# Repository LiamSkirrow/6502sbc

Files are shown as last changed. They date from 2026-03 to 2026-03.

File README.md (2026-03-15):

# 6502 🎉

A minimal implementation of a functional 6502-based system. It has everything that's needed to get going, including a 6522 VIA (for parallel ports/GPIO control) and a 6551 ACIA (for uart connection to a serial terminal).

## Pics
TODO, include screenshots of schematic and PCB. Can I render these automatically based on the current state of the schem/pcb in the repo?

## Memory Map
TODO

## Bootloader
ASM TODO

## Components
TODO

## Tutorial, how to get up and running
TODO, sourcing components, board bring-up, writing your own ASM snippets and loading them into ram via the bootloader+serial chip. How to write your own ISRs etc.

### Development Notes
- consider replacing zero-Ohm resistors with jumper headers, so I can place/replace them without a soldering iron
- add a jumper header to be able to switch between powering the board directly via a 5V USB cable, and an LM7805 linear reg. Three way jumper header to make it impossible to simultaneously select both options.
- rework memory map so that the ROM is only large enough to contain the minimal bootloader (+ a little extra just in case). We only need the ROM to be as large as the bootloader, since the RAM is where the user-code will be loaded into ready for execution, so minimise ROM and maximise RAM util.
  - perhaps rather than sacrifice a small but fixed amount of memory to the bootloader, why not think of a way to utilise the full 64kB RAM chip once the bootloader has completed. There would need to be some kind of dynamic bank-switching involved, possibly involving one output bit of the 6522 GPIO port to adjust the address decoding to no longer enable the ROM, instead always enabling the RAM (except obviously for when accessing the 6522/6551). So, when the bootloader completes and jumps to the starting address of the user program (in RAM), the first instructions should write to a special GPIO bit that switches out the default decode logic for another logic function that keeps the ROM disabled and RAM enabled. This way, we'd be able to utilise the full ROM space and then when its job is complete we could switch to utilising the full RAM space. So we don't need to use small, fixed regions of memory at any one time, instead using potentially the full capacity of the chip.

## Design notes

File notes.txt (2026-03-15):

SIGN OFF CHECKS:
- consider a PCB solder mask colour other than green?
- consider socketing the crystal? so different crystals can be swapped in and out
- add some gnd test hooks for scope probe
- add jumper header to input current path
- make sure EEPROM has enough space for ZIF socket
- address all text on schematic...
- it looks like you can tie RTS to CTS, DSR to DTR to DCD (https://www.youtube.com/watch?v=XVEnxipCIJ0&ab_channel=UnistInc.), make sure each of these signals on the pin header are next to eachother so they can be tied together via a shunt connector if need be
- read through notes on phone, pay attention to each point individually
- what's the deal with the flow control pins? can you just tie them 'inactive' and forget about it???
- EEPROM should be fitted in a ZIF socket
- *** should I put the ZIF socket in a normal dip socket, so the ZIF socket can be removed eventually? ***
- *** verify that ALL packages are actually available to buy BEFORE placing PCB order ***

BOM SIGN OFF CHECKS:
- buy some female-female wires, female-male wires
- at end of PCB layout count up how many 0603 components are being used, check you still have enough in stock (100nF caps...)
- *** verify that ALL packages are actually available to buy BEFORE placing PCB order ***
- check the forward voltage of the 0805 LEDs, resize resistors if necessary
- all parts should be HC *not* HCT or TTL 

Soldering order of components:
- linear regulator
- push button/debounce circuitry
- decode logic + pin headers for address bus access
- clock circuit
- everything else...

MUST DO:
- To verify: (simulation???)
  - clock circuit

- ??? what's the advantage of gating the PHI2 signal -> *** https://wilsonminesco.com/6502primer/addr_decoding.html ***
- verify all the IO chip's max clock frequency capability, run system at max possible frequency

Footprints:
Might need to change:
- LED resistors
- verify crystal footprints

Memory Map:
  ZP     0x0000 - 0x00FF (256 Bytes)
  STACK  0x0100 - 0x01FF (256 Bytes)
  I/O    0x0200 - 0x021F (32 Bytes) 
  - 6551   0x0200 - 0x020F (16 Bytes)
  - 6522   0x0200 - 0x021F (16 Bytes)
  MEM    0x0220 - 0x7FFF (32,224 Bytes)
  -------------------------------------
  ROM    0x8000 - 0xFFFF (32 kBytes)

$$$
if:
- ~13cm x ~15cm
- 4 layer board
- 1.6mm thickness
= $56.29

else:
- 2 layer
= ~$15
$$$

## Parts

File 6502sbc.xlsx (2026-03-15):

Reference | Quantity | Value | Footprint | DONE?
C1 | 1 | 0.22u | Capacitor_SMD:C_0805_2012Metric_Pad1.18x1.45mm_HandSolder | Y
C2 | 1 | 0.1u | Capacitor_SMD:C_0603_1608Metric_Pad1.08x0.95mm_HandSolder | Y
C3 C4 C5 C7 C8 C10 C11 C12 C13 C14 | 10 | 100n | Capacitor_SMD:C_0603_1608Metric_Pad1.08x0.95mm_HandSolder | Y
C6 C15 | 2 | 1u | Capacitor_SMD:C_0805_2012Metric_Pad1.18x1.45mm_HandSolder | Y
C9 | 1 | 30p | Capacitor_SMD:C_0805_2012Metric_Pad1.18x1.45mm_HandSolder | Y
D1 D2 D3 D4 D5 D6 D7 D8 D9 | 9 | LED | LED_SMD:LED_0805_2012Metric_Pad1.15x1.40mm_HandSolder | Y
J1 J3 | 2 | Conn_02x16_Odd_Even | Connector_PinHeader_2.54mm:PinHeader_2x16_P2.54mm_Vertical | Y
J2 | 1 | Conn_01x02 | Connector_PinHeader_2.54mm:PinHeader_1x02_P2.54mm_Vertical | Y
J6 J7 J8 | 3 | Conn_01x03_Male | Connector_PinHeader_2.54mm:PinHeader_1x03_P2.54mm_Vertical | Y
R1 | 1 | 500 | Resistor_SMD:R_0805_2012Metric_Pad1.20x1.40mm_HandSolder | Y
R9 R10 R11 R12 R13 R14 R15 R16 | 8 | 600 | Resistor_SMD:R_0603_1608Metric_Pad1.05x0.95mm_HandSolder | Y
R19 | 1 | 15k | Resistor_SMD:R_0805_2012Metric_Pad1.20x1.40mm_HandSolder | Y
R2 R3 R17 R18 | 4 | 1k | Resistor_SMD:R_0805_2012Metric_Pad1.20x1.40mm_HandSolder | Y
R4 | 1 | 1.5k | Resistor_SMD:R_0805_2012Metric_Pad1.20x1.40mm_HandSolder | Y
R5 | 1 | 3k | Resistor_SMD:R_0805_2012Metric_Pad1.20x1.40mm_HandSolder | Y
R6 R7 R8 | 3 | 3.3k | Resistor_SMD:R_0805_2012Metric_Pad1.20x1.40mm_HandSolder | Y
R20 | 1 | 1M | Resistor_SMD:R_0805_2012Metric_Pad1.20x1.40mm_HandSolder | Y
SW1 SW2 | 2 | SW_Push | Button_Switch_SMD:SW_Push_1P1T_NO_6x6mm_H9.5mm | Y
U1 | 1 | LM7805_TO220 | Package_TO_SOT_THT:TO-220-3_Vertical | Y
U10 | 1 | 74HCT541 | Package_SO:SOIC-20W_7.5x12.8mm_P1.27mm | Y
U2 | 1 | 6502 | Package_DIP:DIP-40_W15.24mm | Y
U3 | 1 | 6522 | Package_DIP:DIP-40_W15.24mm | Y
U4 | 1 | 6551 | Package_DIP:DIP-28_W15.24mm | Y
U5 | 1 | 4081 | Package_SO:SOIC-14W_7.5x9.0mm_P1.27mm | Y
U6 U12 | 2 | 4002 | Package_SO:SOIC-14W_7.5x9.0mm_P1.27mm | Y
U7 | 1 | 28C256 | Package_DIP:DIP-28_W15.24mm | Y
U8 | 1 | FM1808B-SG | Package_DIP:DIP-28_W15.24mm | Y
U9 U11 | 2 | 74HC14 | Package_SO:SOIC-14W_7.5x9.0mm_P1.27mm | Y
Y1 | 1 | 1MHz | Crystal:Resonator-2Pin_W6.0mm_H3.0mm | Y
Y2 | 1 | 1.8432MHz | Crystal:Resonator-2Pin_W6.0mm_H3.0mm | Y
R21 R22 R23 | 3 | 0Ohm | 805 | Y
ADDITIONAL COMPONENTS |  | REFER TO DEV NOTES (shunts etc…)
2 way shunt header | 2 |  |  | Y
3 way shunt header | 1 |  |  | N | going with 0 ohm resistors instead
f-f wires | 16 |  |  | Y
f-m wires | 16 |  |  | Y
stand off legs | 4 |  |  | Y
ZIF socket | 1
soldering tweezers |  |  |  | Y

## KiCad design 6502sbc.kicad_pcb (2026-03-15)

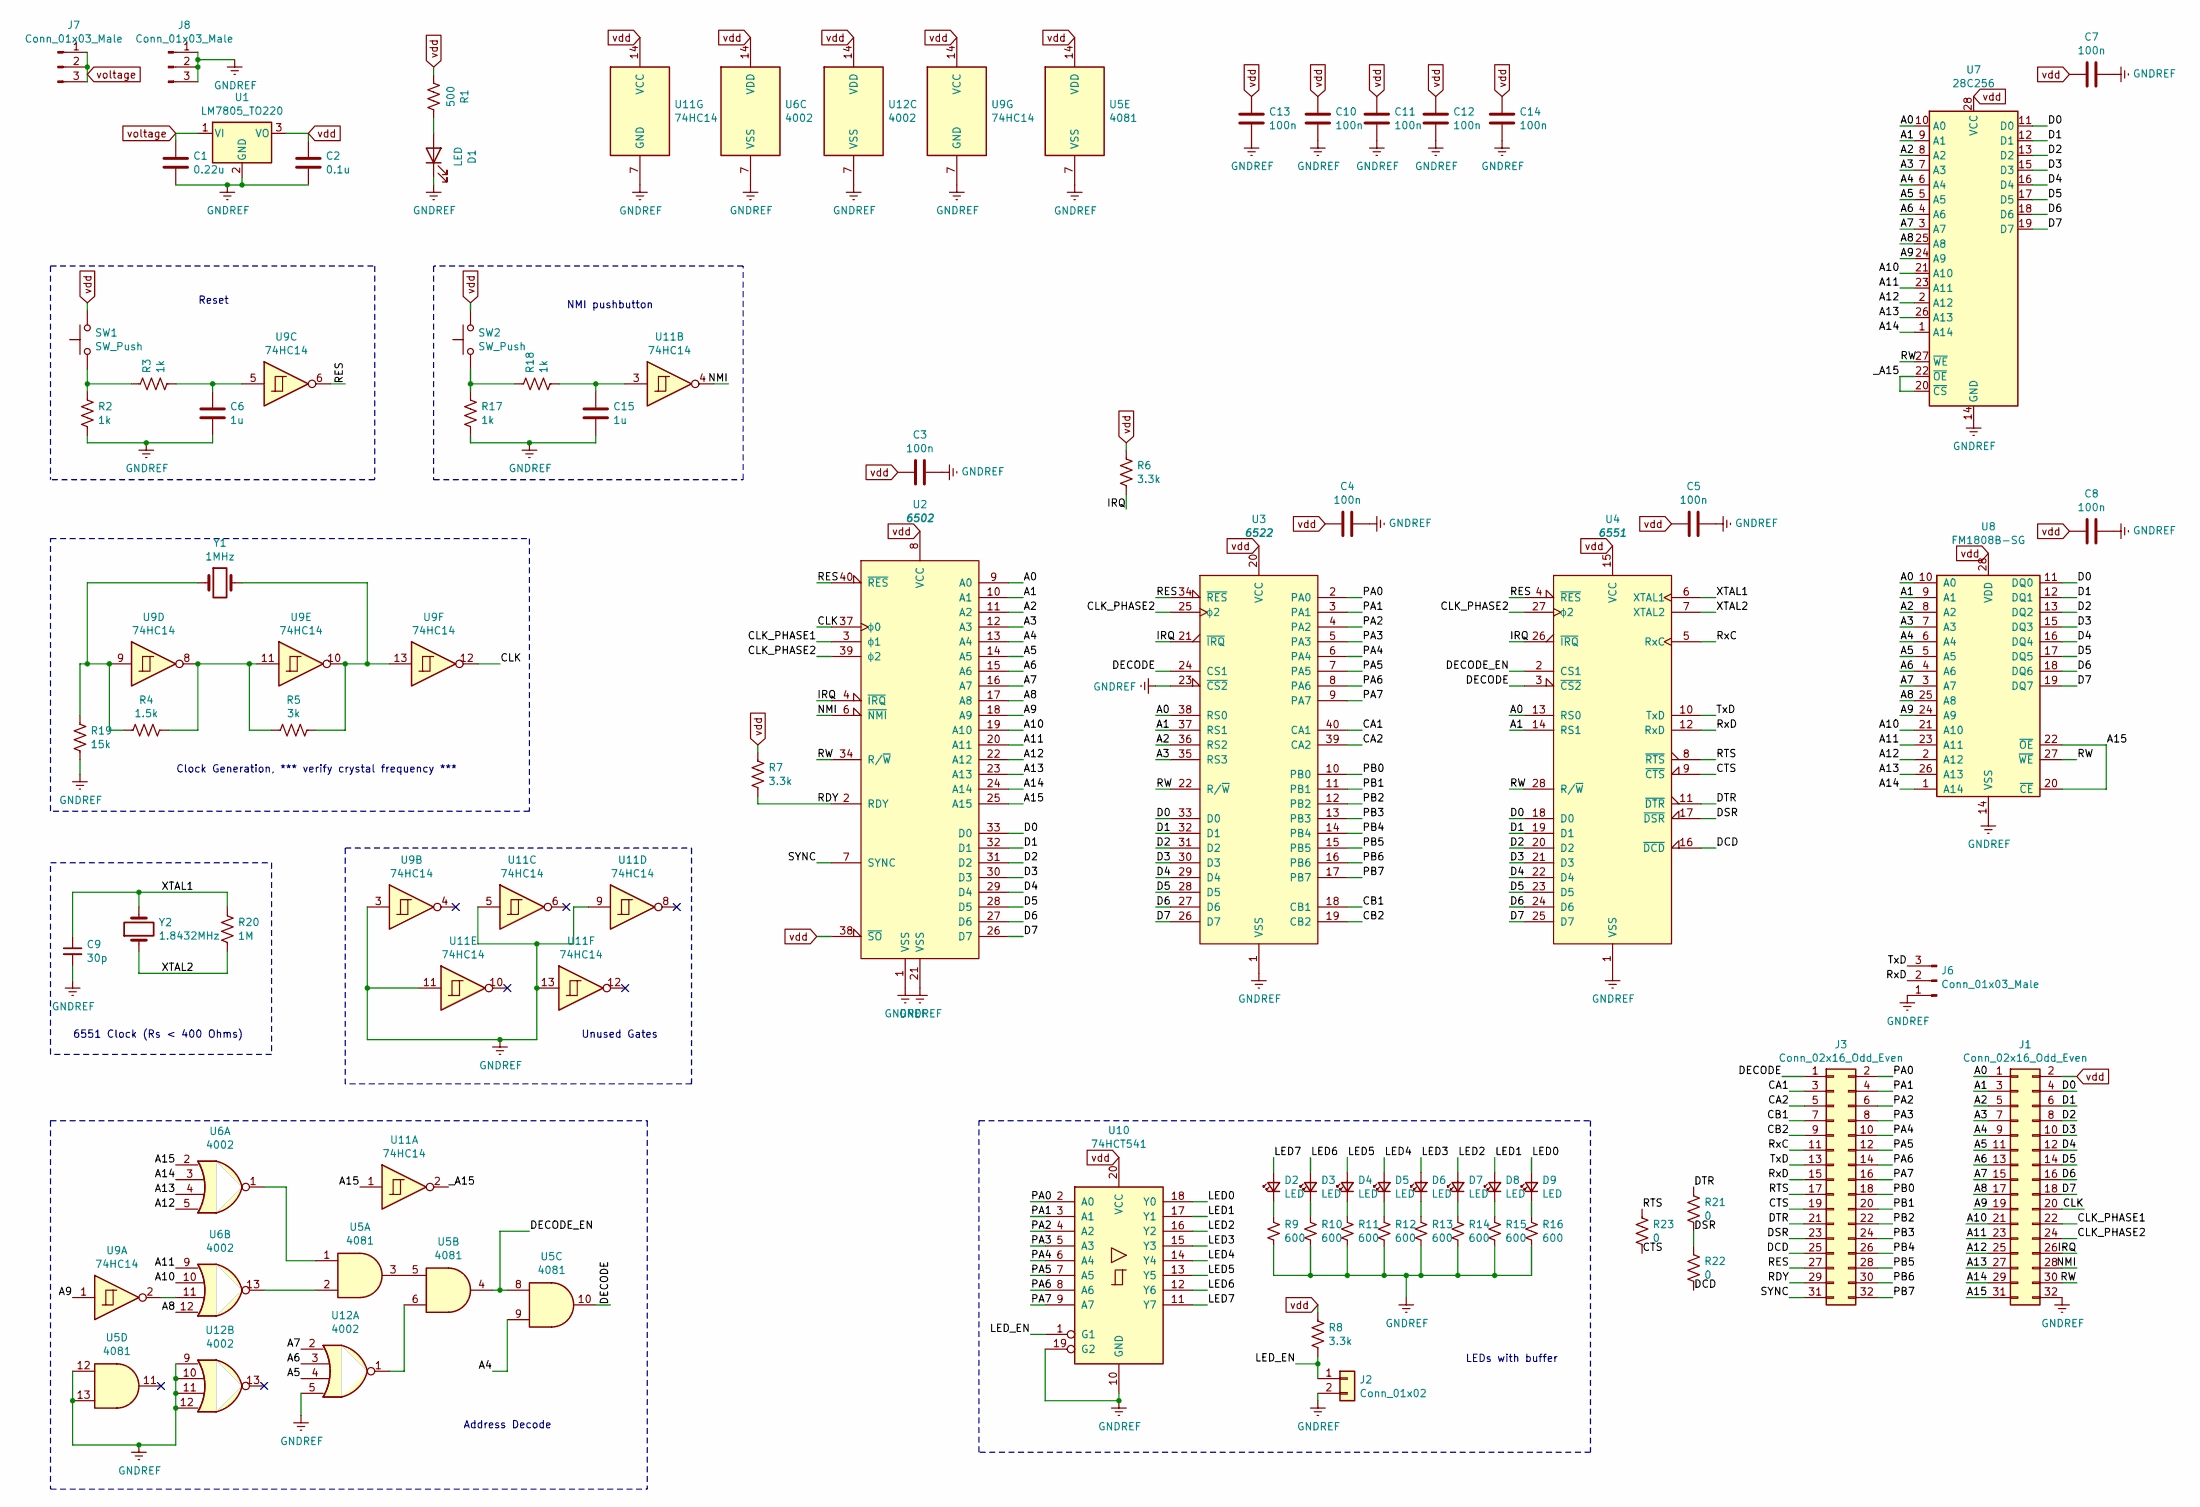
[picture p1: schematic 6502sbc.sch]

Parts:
C1: 0.22u; C_0805_2012Metric_Pad1.18x1.45mm_HandSolder
C2: 0.1u; C_0603_1608Metric_Pad1.08x0.95mm_HandSolder
C3, C4, C5, C7, C8, C10, C11, C12, C13, C14: 100n; C_0603_1608Metric_Pad1.08x0.95mm_HandSolder
C6, C15: 1u; C_0805_2012Metric_Pad1.18x1.45mm_HandSolder
C9: 30p; C_0805_2012Metric_Pad1.18x1.45mm_HandSolder
D1, D2, D3, D4, D5, D6, D7, D8, D9: LED; LED_0805_2012Metric_Pad1.15x1.40mm_HandSolder
J1, J3: Conn_02x16_Odd_Even; PinHeader_2x16_P2.54mm_Vertical
J2: Conn_01x02; PinHeader_1x02_P2.54mm_Vertical
J6, J7, J8: Conn_01x03_Male; PinHeader_1x03_P2.54mm_Vertical
R1: 500; R_0805_2012Metric_Pad1.20x1.40mm_HandSolder
R2, R3, R17, R18: 1k; R_0805_2012Metric_Pad1.20x1.40mm_HandSolder
R4: 1.5k; R_0805_2012Metric_Pad1.20x1.40mm_HandSolder
R5: 3k; R_0805_2012Metric_Pad1.20x1.40mm_HandSolder
R6, R7, R8: 3.3k; R_0805_2012Metric_Pad1.20x1.40mm_HandSolder
R9, R10, R11, R12, R13, R14, R15, R16: 600; R_0603_1608Metric_Pad1.05x0.95mm_HandSolder
R19: 15k; R_0805_2012Metric_Pad1.20x1.40mm_HandSolder
R20: 1M; R_0805_2012Metric_Pad1.20x1.40mm_HandSolder
R21, R22, R23: 0; R_0805_2012Metric_Pad1.20x1.40mm_HandSolder
SW1, SW2: SW_Push; SW_Push_1P1T_NO_6x6mm_H9.5mm
U1: LM7805_TO220; TO-220-3_Vertical
U2: 6502; DIP-40_W15.24mm
U3: 6522; DIP-40_W15.24mm
U4: 6551; DIP-28_W15.24mm
U5: 4081; SO-14_3.9x8.65mm_P1.27mm
U6, U12: 4002; SO-14_3.9x8.65mm_P1.27mm
U7: 28C256; DIP-28_W15.24mm
U8: FM1808B-SG; DIP-28_W15.24mm
U9, U11: 74HC14; SO-14_3.9x8.65mm_P1.27mm
U10: 74HCT541; SOIC-20W_7.5x12.8mm_P1.27mm
Y1: 1MHz; Resonator-2Pin_W6.0mm_H3.0mm
Y2: 1.8432MHz; Resonator-2Pin_W6.0mm_H3.0mm

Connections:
/A0: J1.1, U2.9 (A0), U3.38 (RS0), U4.13 (RS0), U7.10 (A0), U8.10 (A0)
/A1: J1.3, U2.10 (A1), U3.37 (RS1), U4.14 (RS1), U7.9 (A1), U8.9 (A1)
/A2: J1.5, U2.11 (A2), U3.36 (RS2), U7.8 (A2), U8.8 (A2)
/A3: J1.7, U2.12 (A3), U3.35 (RS3), U7.7 (A3), U8.7 (A3)
/A4: J1.9, U2.13 (A4), U5.9, U7.6 (A4), U8.6 (A4)
/A5: J1.11, U2.14 (A5), U7.5 (A5), U8.5 (A5), U12.4
/A6: J1.13, U2.15 (A6), U7.4 (A6), U8.4 (A6), U12.3
/A7: J1.15, U2.16 (A7), U7.3 (A7), U8.3 (A7), U12.2
/A8: J1.17, U2.17 (A8), U6.12, U7.25 (A8), U8.25 (A8)
/A9: J1.19, U2.18 (A9), U7.24 (A9), U8.24 (A9), U9.1
/A10: J1.21, U2.19 (A10), U6.10, U7.21 (A10), U8.21 (A10)
/A11: J1.23, U2.20 (A11), U6.9, U7.23 (A11), U8.23 (A11)
/A12: J1.25, U2.22 (A12), U6.5, U7.2 (A12), U8.2 (A12)
/A13: J1.27, U2.23 (A13), U6.4, U7.26 (A13), U8.26 (A13)
/A14: J1.29, U2.24 (A14), U6.3, U7.1 (A14), U8.1 (A14)
/A15: J1.31, U2.25 (A15), U6.2, U8.20 (~CE~), U8.22 (~OE~), U11.1
/CA1: J3.3, U3.40 (CA1)
/CA2: J3.5, U3.39 (CA2)
/CB1: J3.7, U3.18 (CB1)
/CB2: J3.9, U3.19 (CB2)
/CLK: J1.20, U2.37 (ϕ0), U9.12
/CLK_PHASE1: J1.22, U2.3 (ϕ1)
/CLK_PHASE2: J1.24, U2.39 (ϕ2), U3.25 (ϕ2), U4.27 (ϕ2)
/CTS: J3.19, R23.2, U4.9 (~CTS)
/D0: J1.4, U2.33 (D0), U3.33 (D0), U4.18 (D0), U7.11 (D0), U8.11 (DQ0)
/D1: J1.6, U2.32 (D1), U3.32 (D1), U4.19 (D1), U7.12 (D1), U8.12 (DQ1)
/D2: J1.8, U2.31 (D2), U3.31 (D2), U4.20 (D2), U7.13 (D2), U8.13 (DQ2)
/D3: J1.10, U2.30 (D3), U3.30 (D3), U4.21 (D3), U7.15 (D3), U8.15 (DQ3)
/D4: J1.12, U2.29 (D4), U3.29 (D4), U4.22 (D4), U7.16 (D4), U8.16 (DQ4)
/D5: J1.14, U2.28 (D5), U3.28 (D5), U4.23 (D5), U7.17 (D5), U8.17 (DQ5)
/D6: J1.16, U2.27 (D6), U3.27 (D6), U4.24 (D6), U7.18 (D6), U8.18 (DQ6)
/D7: J1.18, U2.26 (D7), U3.26 (D7), U4.25 (D7), U7.19 (D7), U8.19 (DQ7)
/DCD: J3.25, R22.2, U4.16 (~DCD)
/DECODE: J3.1, U3.24 (CS1), U4.3 (~CS2), U5.10
/DECODE_EN: U4.2 (CS1), U5.4, U5.8
/DSR: J3.23, R21.2, R22.1, U4.17 (~DSR)
/DTR: J3.21, R21.1, U4.11 (~DTR)
/IRQ: J1.26, R6.2, U2.4 (~IRQ), U3.21 (~IRQ), U4.26 (~IRQ)
/LED0: D9.2 (A), U10.18 (Y0)
/LED1: D8.2 (A), U10.17 (Y1)
/LED2: D7.2 (A), U10.16 (Y2)
/LED3: D6.2 (A), U10.15 (Y3)
/LED4: D5.2 (A), U10.14 (Y4)
/LED5: D4.2 (A), U10.13 (Y5)
/LED6: D3.2 (A), U10.12 (Y6)
/LED7: D2.2 (A), U10.11 (Y7)
/LED_EN: J2.1, R8.2, U10.1 (G1)
/NMI: J1.28, U2.6 (~NMI), U11.4
/PA0: J3.2, U3.2 (PA0), U10.2 (A0)
/PA1: J3.4, U3.3 (PA1), U10.3 (A1)
/PA2: J3.6, U3.4 (PA2), U10.4 (A2)
/PA3: J3.8, U3.5 (PA3), U10.5 (A3)
/PA4: J3.10, U3.6 (PA4), U10.6 (A4)
/PA5: J3.12, U3.7 (PA5), U10.7 (A5)
/PA6: J3.14, U3.8 (PA6), U10.8 (A6)
/PA7: J3.16, U3.9 (PA7), U10.9 (A7)
/PB0: J3.18, U3.10 (PB0)
/PB1: J3.20, U3.11 (PB1)
/PB2: J3.22, U3.12 (PB2)
/PB3: J3.24, U3.13 (PB3)
/PB4: J3.26, U3.14 (PB4)
/PB5: J3.28, U3.15 (PB5)
/PB6: J3.30, U3.16 (PB6)
/PB7: J3.32, U3.17 (PB7)
/RDY: J3.29, R7.2, U2.2 (RDY)
/RES: J3.27, U2.40 (~RES), U3.34 (~RES), U4.4 (~RES), U9.6
/RTS: J3.17, R23.1, U4.8 (~RTS)
/RW: J1.30, U2.34 (R/~W), U3.22 (R/~W), U4.28 (R/~W), U7.27 (~WE), U8.27 (~WE~)
/RxC: J3.11, U4.5 (RxC)
/RxD: J3.15, J6.2, U4.12 (RxD)
/SYNC: J3.31, U2.7 (SYNC)
/TxD: J3.13, J6.3, U4.10 (TxD)
/XTAL1: C9.1, R20.1, U4.6 (XTAL1), Y2.2
/XTAL2: R20.2, U4.7 (XTAL2), Y2.1
/_A15: U7.20 (~CS), U7.22 (~OE), U11.2
GNDREF: C1.2, C2.2, C3.1, C4.1, C5.1, C6.1, C7.1, C8.1, C9.2, C10.2, C11.2, C12.2, C13.2, C14.2, C15.1, D1.1 (K), J1.32, J2.2, J6.1, J8.1, J8.2, J8.3, R2.2, R9.2, R10.2, R11.2, R12.2, R13.2, R14.2, R15.2, R16.2, R17.2, R19.2, U1.2 (GND), U2.1 (VSS), U2.21 (VSS), U3.1 (VSS), U3.23 (~CS2), U4.1 (VSS), U5.7 (VSS), U5.12, U5.13, U6.7 (VSS), U7.14 (GND), U8.14 (VSS), U9.3, U9.7 (GND), U10.10 (GND), U10.19 (G2), U11.5, U11.7 (GND), U11.9, U11.11, U11.13, U12.5, U12.7 (VSS), U12.9, U12.10, U12.11, U12.12
unnamed: C6.2, R3.2, U9.5
unnamed: C15.2, R18.2, U11.3
unnamed: D1.2 (A), R1.1
unnamed: D2.1 (K), R9.1
unnamed: D3.1 (K), R10.1
unnamed: D4.1 (K), R11.1
unnamed: D5.1 (K), R12.1
unnamed: D6.1 (K), R13.1
unnamed: D7.1 (K), R14.1
unnamed: D8.1 (K), R15.1
unnamed: D9.1 (K), R16.1
unnamed: R2.1, R3.1, SW1.1
unnamed: R4.1, R5.2, U9.8, U9.11
unnamed: R5.1, U9.10, U9.13, Y1.2
unnamed: R17.1, R18.1, SW2.1
unnamed: R4.2, R19.1, U9.9, Y1.1
unnamed: U5.1, U6.1
unnamed: U5.2, U6.13
unnamed: U5.3, U5.5
unnamed: U6.11, U9.2
unnamed: U5.6, U12.1
vdd: C2.1, C3.2, C4.2, C5.2, C7.2, C8.2, C10.1, C11.1, C12.1, C13.1, C14.1, J1.2, R1.2, R6.1, R7.1, R8.1, SW1.2, SW2.2, U1.3 (VO), U2.8 (VCC), U2.38 (~SO), U3.20 (VCC), U4.15 (VCC), U5.14 (VDD), U6.14 (VDD), U7.28 (VCC), U8.28 (VDD), U9.14 (VCC), U10.20 (VCC), U11.14 (VCC), U12.14 (VDD)
voltage: C1.1, J7.1, J7.2, J7.3, U1.1 (VI)

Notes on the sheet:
Reset
Address Decode
Clock Generation, *** verify crystal frequency ***
6551 Clock (Rs < 400 Ohms)
LEDs with buffer
NMI pushbutton
Unused Gates

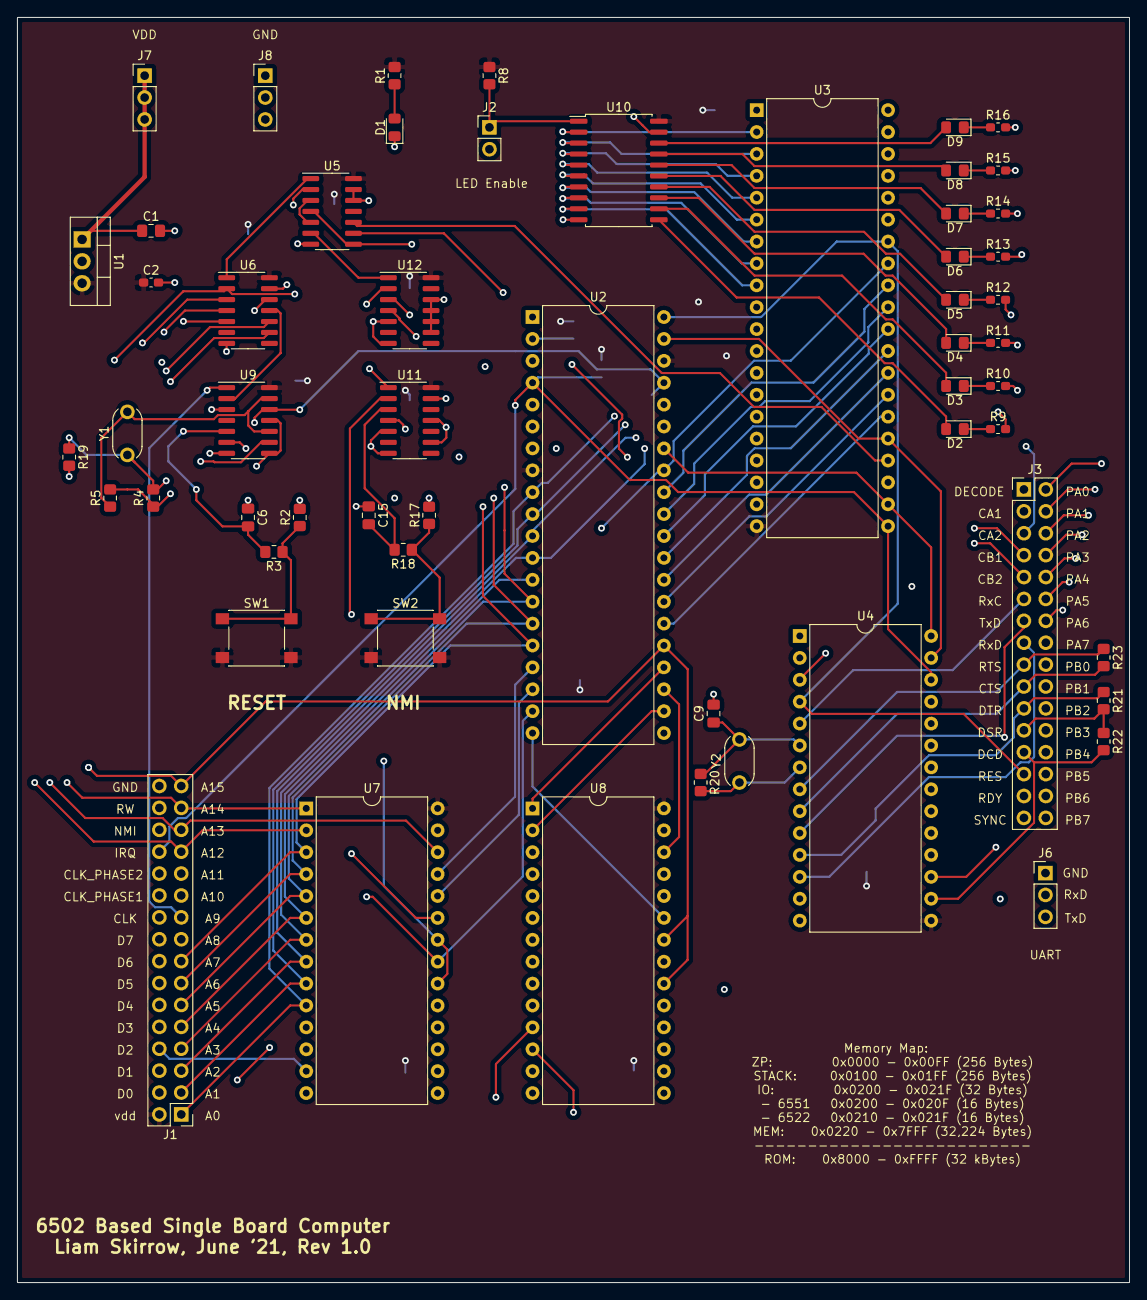
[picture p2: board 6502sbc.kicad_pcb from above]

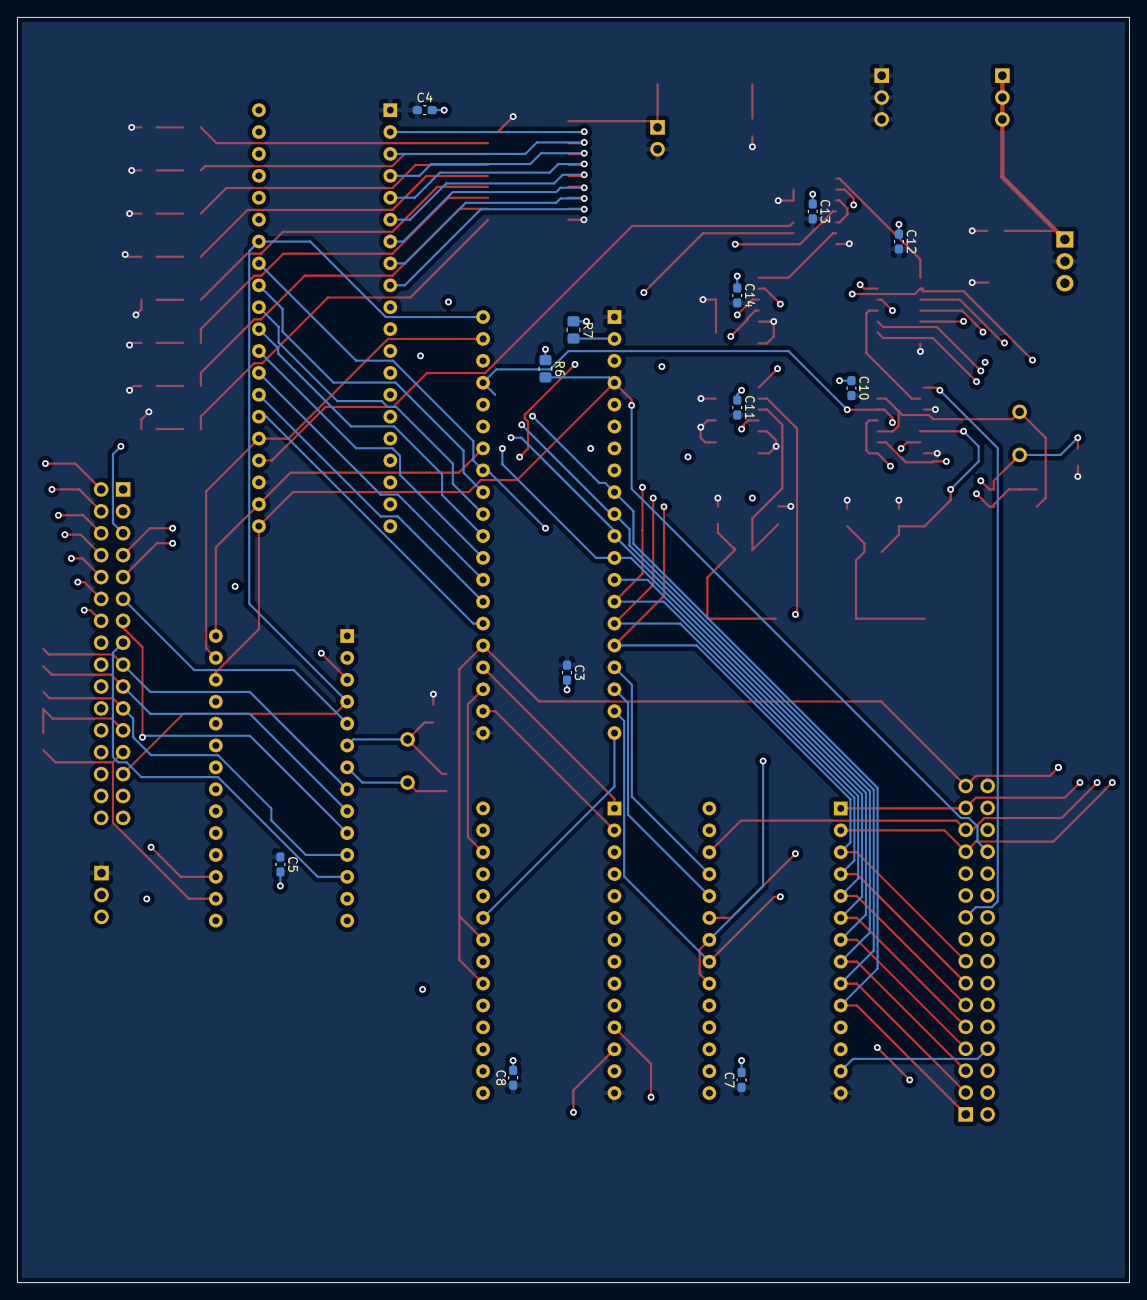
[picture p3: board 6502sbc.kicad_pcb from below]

Board: 4 copper layers, 129.0 x 146.8 mm, 69 parts (12 on the bottom side), 99 nets.
